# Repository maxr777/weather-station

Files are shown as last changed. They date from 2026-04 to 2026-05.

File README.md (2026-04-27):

# Weather Station
ESP32-based weather station built with ESP-IDF, no third-party sensor libraries. A handmade rewrite of an earlier Arduino IDE version that relied on libraries. Also taken further: soldered onto a perfboard with a 3D printed enclosure instead of a breadboard.

Reads temperature, humidity, and pressure via a BME280 over I2C, monitors air quality with a PMS5003 over UART, and displays everything on an SH1106 OLED. A few diagnostic LEDs signal hardware faults on startup.

All sensor drivers written from scratch against the datasheets. Structured as pure header-only libraries — an experiment after building projects with both the classic .h/.c split and unity builds. Uses Raylib naming conventions - I'd use [Tiger Style](https://tigerstyle.dev/#nouns-and-verbs) if starting it today. Font by [petabyt](https://github.com/petabyt/font). Startup logo generated with Claude.

## Demo

*Low res thumbnails — click to watch on YouTube*

Breadboard demo (https://youtu.be/4yA_y9Lus5Y)

Perfboard build (https://youtu.be/DK9z5tJ5IRI)

## Schematic
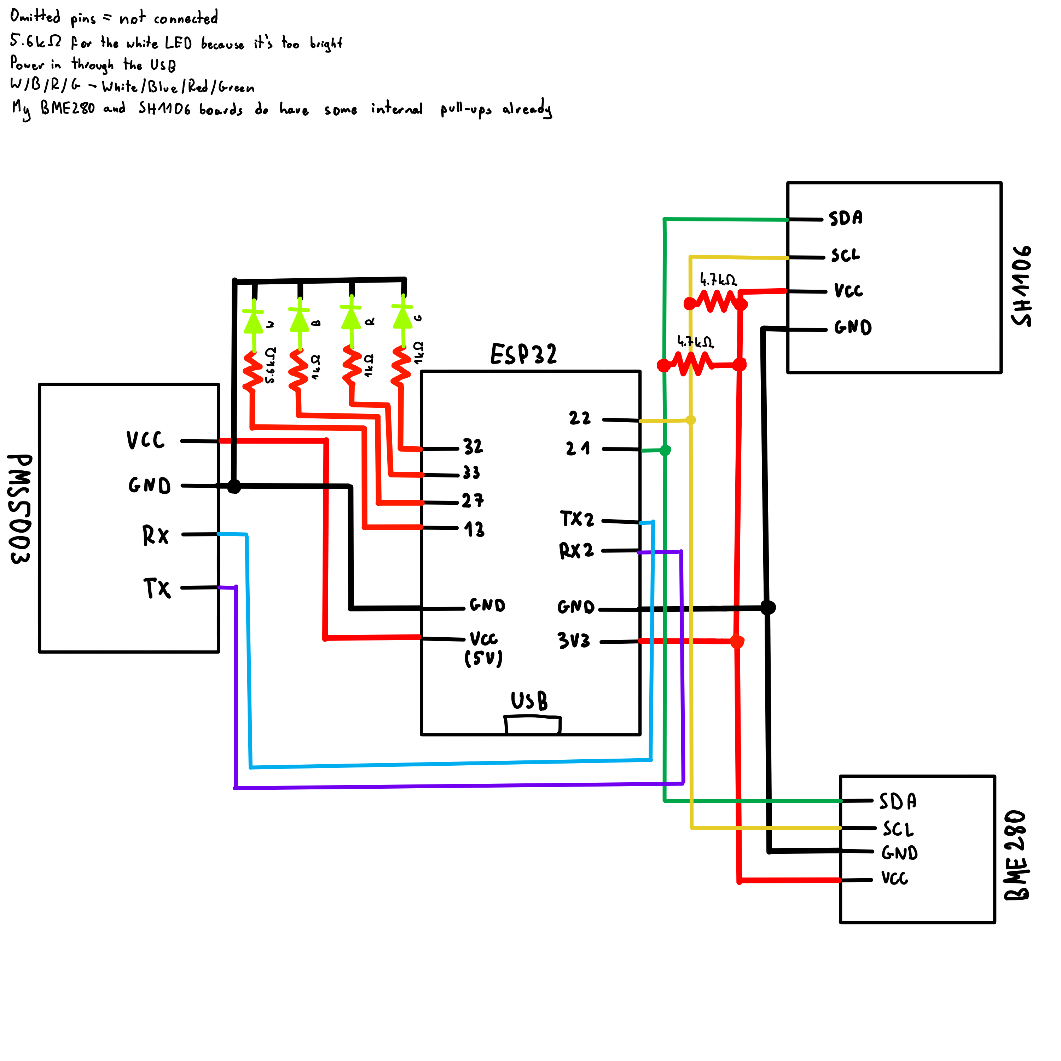
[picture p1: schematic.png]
Schematic


## Build
`idf.py build flash monitor` (run from the root directory, not `main/`)

## Notes
- Enum names ended up too verbose - need to be more conservative with it
- Tiger Style's big-endian naming is so much better (`BME280_setup()` over `setup_BME280()`) - it reads better and works great with autocomplete
- camelCase is harder to read and is a headache sometimes (e.g. `0` followed by `O`, or `GetLEDGPIO`) - definitely use snake_case

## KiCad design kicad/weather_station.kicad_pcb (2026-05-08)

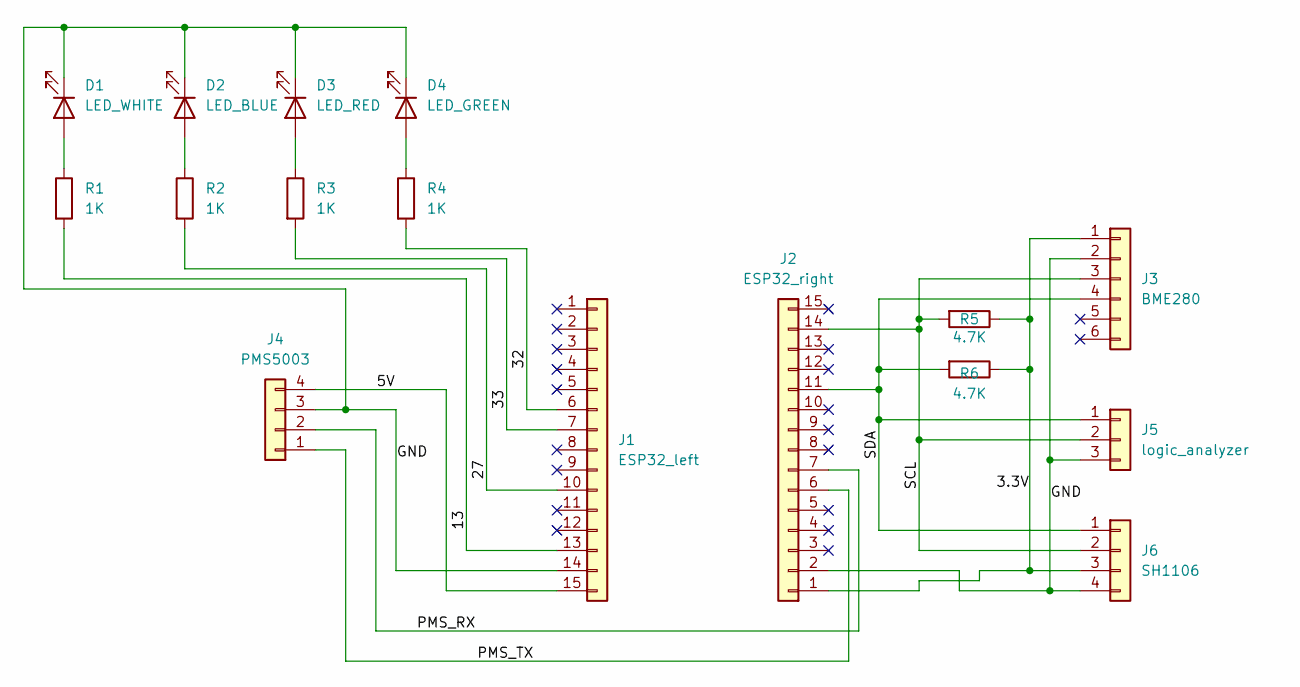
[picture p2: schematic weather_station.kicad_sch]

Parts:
D1: LED_WHITE; LED_0805_2012Metric
D2: LED_BLUE; LED_0805_2012Metric
D3: LED_RED; LED_0805_2012Metric
D4: LED_GREEN; LED_0805_2012Metric
J1: ESP32_left; PinHeader_1x15_P2.54mm_Vertical
J2: ESP32_right; PinHeader_1x15_P2.54mm_Vertical
J3: BME280; PinHeader_1x06_P2.54mm_Vertical
J4: PMS5003; PinHeader_1x04_P2.54mm_Vertical
J5: logic_analyzer; PinHeader_1x03_P2.54mm_Vertical
J6: SH1106; PinHeader_1x04_P2.54mm_Vertical
R1, R2, R3, R4: 1K; R_0805_2012Metric
R5, R6: 4.7K; R_0805_2012Metric

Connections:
/3.3V: J2.1, J3.1, J6.3, R5.1, R6.1
/5V: J1.15, J4.4
/13: J1.13, R1.2
/27: J1.10, R2.2
/32: J1.6, R4.2
/33: J1.7, R3.2
/GND: D1.1 (K), D2.1 (K), D3.1 (K), D4.1 (K), J1.14, J2.2, J3.2, J4.3, J5.3, J6.4
/PMS_RX: J2.7, J4.2
/PMS_TX: J2.6, J4.1
/SCL: J2.14, J3.3, J5.2, J6.2, R5.2
/SDA: J2.11, J3.4, J5.1, J6.1, R6.2
unnamed: D1.2 (A), R1.1
unnamed: D2.2 (A), R2.1
unnamed: D3.2 (A), R3.1
unnamed: D4.2 (A), R4.1

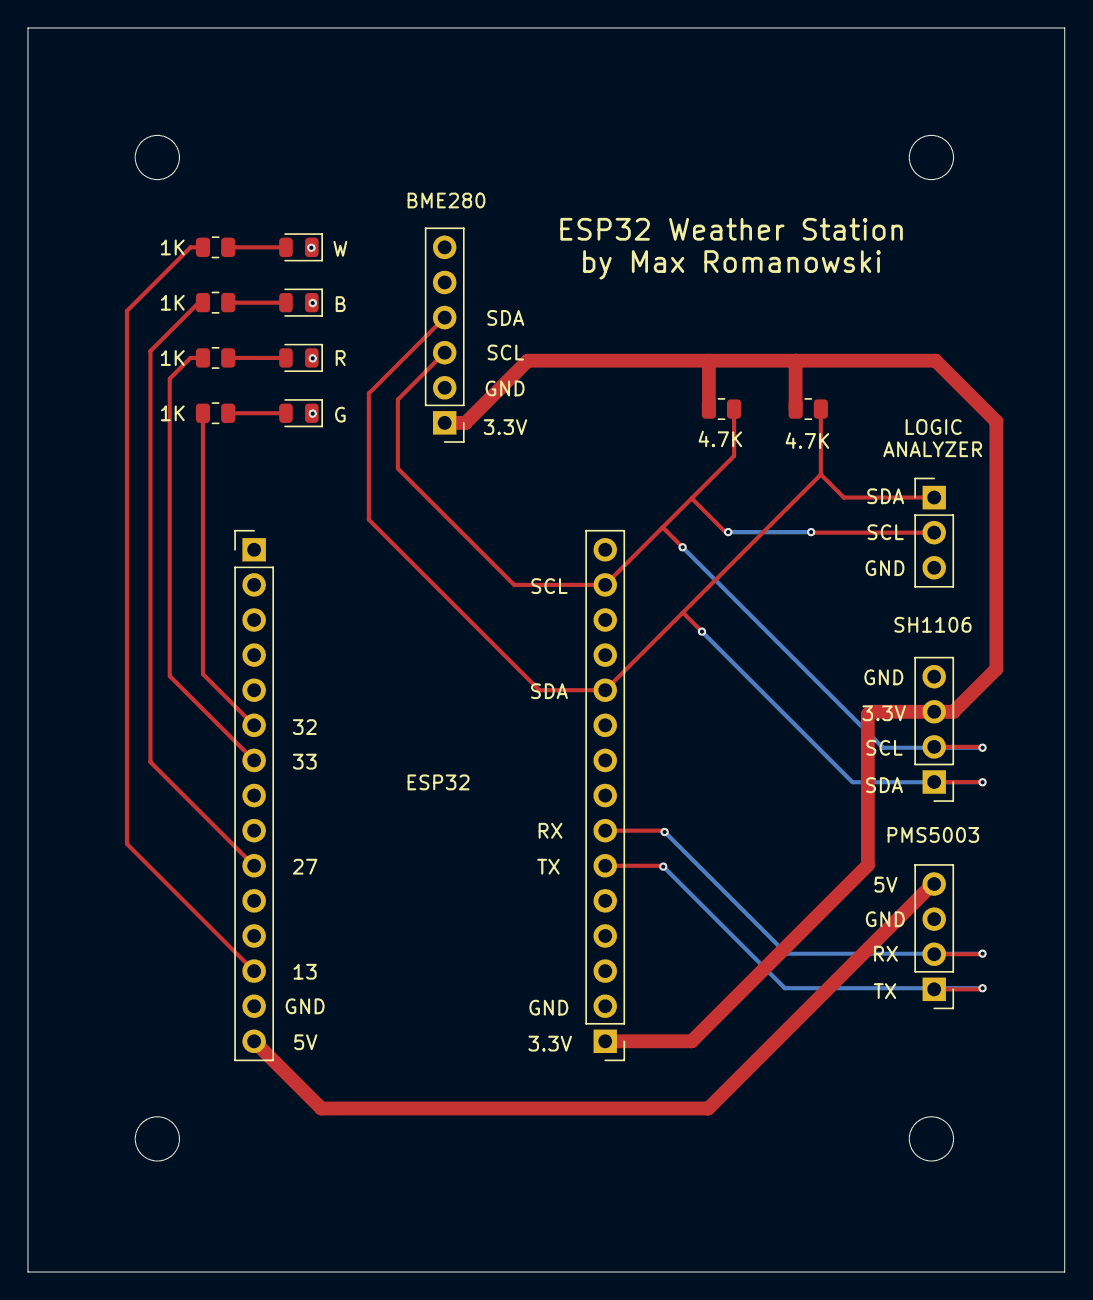
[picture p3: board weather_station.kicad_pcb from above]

Board: 2 copper layers, 75.0 x 90.0 mm, 20 parts (0 on the bottom side), 15 nets.

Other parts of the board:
H1, H2, H3, H4: MountingHole_3.2mm_M3

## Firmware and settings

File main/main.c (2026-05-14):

#include "bme280.h"
#include "driver/gpio.h"
#include "driver/i2c_master.h"
#include "freertos/FreeRTOS.h"
#include "freertos/task.h"
#include "led.h"
#include "pms5003.h"
#include "sh1106.h"
#include <stdio.h>

void app_main(void) {
	// Setup the LED GPIOs as output
	gpio_reset_pin(WHITE_LED_GPIO);
	gpio_set_direction(WHITE_LED_GPIO, GPIO_MODE_OUTPUT);
	gpio_reset_pin(BLUE_LED_GPIO);
	gpio_set_direction(BLUE_LED_GPIO, GPIO_MODE_OUTPUT);
	gpio_reset_pin(RED_LED_GPIO);
	gpio_set_direction(RED_LED_GPIO, GPIO_MODE_OUTPUT);
	gpio_reset_pin(GREEN_LED_GPIO);
	gpio_set_direction(GREEN_LED_GPIO, GPIO_MODE_OUTPUT);

	// Setup the i2c bus
	i2c_master_bus_config_t busConfig = {};
	busConfig.i2c_port = -1;
	busConfig.sda_io_num = 21;
	busConfig.scl_io_num = 22;
	busConfig.clk_source = I2C_CLK_SRC_DEFAULT;
	busConfig.glitch_ignore_cnt = 7;
	busConfig.intr_priority = 0;
	busConfig.trans_queue_depth = 0;
	busConfig.flags.enable_internal_pullup = 1;
	busConfig.flags.allow_pd = 0;

	i2c_master_bus_handle_t masterBusHandle;
	ESP_ERROR_CHECK(i2c_new_master_bus(&busConfig, &masterBusHandle));

	// Setup the sensors
	EnableLED(WHITE);
	SH1106 sh1106 = SetupSH1106(masterBusHandle);

	EnableLED(BLUE);
	BME280 bme280 = SetupBME280(masterBusHandle);

	EnableLED(RED);
	PMS5003 pms5003 = SetupPMS5003();

	EnableLED(GREEN);
	vTaskDelay(pdMS_TO_TICKS(1000));

	DisableLED(WHITE);
	DisableLED(BLUE);
	DisableLED(RED);
	DisableLED(GREEN);

	while (true) {
		GetWeatherReadingsErrorCodes BME280ErrorCode = GetWeatherReadings(&bme280);
		GetAirQualityErrorCodes PMS5003ErrorCode = GetAirQuality(&pms5003);

		char temp[20];
		char humidity[20];
		char pressure[20];
		char pm10[20];
		char pm25[20];
		char pm100[20];

		if (BME280ErrorCode == BME_OK) {
			snprintf(temp, sizeof(temp), "T: %.0f C", bme280.temperature);
			snprintf(humidity, sizeof(humidity), "H: %.0f%%", bme280.humidity);
			snprintf(pressure, sizeof(pressure), "P: %.0f hPa", bme280.pressure / 100);
			DisableLED(BLUE);
		} else {
			ESP_LOGE("BME280", "%s", GetWeatherReadingsErrorCodesToStr(BME280ErrorCode));
			EnableLED(BLUE);
			snprintf(temp, sizeof(temp), "T: %.0f C*", bme280.temperature);
			snprintf(humidity, sizeof(humidity), "H: %.0f%%*", bme280.humidity);
			snprintf(pressure, sizeof(pressure), "P: %.0f hPa*", bme280.pressure / 100);
			RestartBME280(masterBusHandle, &bme280);
		}

		if (PMS5003ErrorCode == PMS_OK) {
			DisableLED(RED);
			snprintf(pm10, sizeof(pm10), "PM 1.0: %d (%s)", pms5003.pm10,
				 GetPM10Quality(pms5003.pm10));
			snprintf(pm25, sizeof(pm25), "PM 2.5: %d (%s)", pms5003.pm25,
				 GetPM25Quality(pms5003.pm25));
			snprintf(pm100, sizeof(pm100), "PM 10:  %d (%s)", pms5003.pm100,
				 GetPM100Quality(pms5003.pm100));
		} else {
			ESP_LOGE("PMS5003", "%s", GetAirQualityErrorCodesToStr(PMS5003ErrorCode));
			EnableLED(RED);
			snprintf(pm10, sizeof(pm10), "PM 1.0: %d (%s)*", pms5003.pm10,
				 GetPM10Quality(pms5003.pm10));
			snprintf(pm25, sizeof(pm25), "PM 2.5: %d (%s)*", pms5003.pm25,
				 GetPM25Quality(pms5003.pm25));
			snprintf(pm100, sizeof(pm100), "PM 10:  %d (%s)*", pms5003.pm100,
				 GetPM100Quality(pms5003.pm100));
		}

		SH1106ClearScreen(&sh1106);
		SH1106PrintText(&sh1106, temp, 1);
		SH1106PrintText(&sh1106, humidity, 2);
		SH1106PrintText(&sh1106, pressure, 3);
		SH1106PrintText(&sh1106, pm10, 4);
		SH1106PrintText(&sh1106, pm25, 5);
		SH1106PrintText(&sh1106, pm100, 6);
		SH1106FlushErrorCodes SH1106ErrorCode = SH1106Flush(&sh1106);
		if (SH1106ErrorCode != SH_OK) {
			ESP_LOGE("SH1106", "%s", FlushErrorCodesToStr(SH1106ErrorCode));
			EnableLED(WHITE);
		} else {
			DisableLED(WHITE);
		}

		fflush(stdout);
		vTaskDelay(1000 / portTICK_PERIOD_MS);
	}
}

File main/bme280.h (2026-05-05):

#ifndef BME280_H
#define BME280_H

#include "driver/i2c_master.h"
#include "esp_log.h"
#include "esp_system.h"
#include "freertos/FreeRTOS.h"
#include "freertos/task.h"
#include "types.h"

#define BME280_ADDR 0x76

typedef struct {
	u16 T1;
	i16 T2;
	i16 T3;
	u16 P1;
	i16 P2;
	i16 P3;
	i16 P4;
	i16 P5;
	i16 P6;
	i16 P7;
	i16 P8;
	i16 P9;
	u8 H1;
	i16 H2;
	u8 H3;
	i16 H4;
	i16 H5;
	i8 H6;
} BME280Calibration;

typedef struct {
	i2c_master_dev_handle_t handle;
	i2c_device_config_t config;
	BME280Calibration offsets;
	// shared variable needed for pressure and humidity compensation
	i32 t_fine;
	float temperature;
	float humidity;
	float pressure;
} BME280;

static inline BME280 SetupBME280(i2c_master_bus_handle_t masterBusHandle) {
	BME280 bme = {};

	{
		bool boot = false;
		for (int i = 0; i < 5; ++i) {
			if (i2c_master_probe(masterBusHandle, BME280_ADDR, pdMS_TO_TICKS(100)) != ESP_OK) {
				ESP_LOGW("BME280", "Weather sensor not found, retrying...");
				vTaskDelay(pdMS_TO_TICKS(250));
			} else {
				boot = true;
				break;
			}
		}
		if (!boot) esp_restart();
	}

	bme.config.dev_addr_length = I2C_ADDR_BIT_LEN_7;
	bme.config.device_address = BME280_ADDR;
	bme.config.scl_speed_hz = 100000;

	ESP_ERROR_CHECK(i2c_master_bus_add_device(masterBusHandle, &bme.config, &bme.handle));

	// reset - write 0xB6 to 0xE0
	{
		uint8_t buf[2] = {0xE0, 0xB6};
		ESP_ERROR_CHECK(i2c_master_transmit(bme.handle, buf, 2, 100));

		// wait for the chip to come back
		vTaskDelay(pdMS_TO_TICKS(10));
	}

	// check chip id - read 0xD0, should be 0x60
	{
		uint8_t reg = 0xD0;
		uint8_t val = 0;
		ESP_ERROR_CHECK(i2c_master_transmit_receive(bme.handle, &reg, 1, &val, sizeof(val), 100));
		if (val != 0x60) {
			ESP_LOGE("BME280", "Wrong chip ID: expected 0x60, got 0x%02X", val);
			esp_restart();
		}
	}

	// read the offset values - they're used for calibration of each bme280, as there are factory variances
	// so you apply the offsets to the raw values you get the get the actual values
	{
		u8 reg = 0x88;
		u8 raw[24];
		ESP_ERROR_CHECK(i2c_master_transmit_receive(bme.handle, &reg, 1, raw, sizeof(raw), 100));

		bme.offsets.T1 = (u16)((u16)raw[1] << 8 | raw[0]);
		bme.offsets.T2 = (i16)((u16)raw[3] << 8 | raw[2]);
		bme.offsets.T3 = (i16)((u16)raw[5] << 8 | raw[4]);
		bme.offsets.P1 = (u16)((u16)raw[7] << 8 | raw[6]);
		bme.offsets.P2 = (i16)((u16)raw[9] << 8 | raw[8]);
		bme.offsets.P3 = (i16)((u16)raw[11] << 8 | raw[10]);
		bme.offsets.P4 = (i16)((u16)raw[13] << 8 | raw[12]);
		bme.offsets.P5 = (i16)((u16)raw[15] << 8 | raw[14]);
		bme.offsets.P6 = (i16)((u16)raw[17] << 8 | raw[16]);
		bme.offsets.P7 = (i16)((u16)raw[19] << 8 | raw[18]);
		bme.offsets.P8 = (i16)((u16)raw[21] << 8 | raw[20]);
		bme.offsets.P9 = (i16)((u16)raw[23] << 8 | raw[22]);

		u8 h1reg = 0xA1;
		ESP_ERROR_CHECK(i2c_master_transmit_receive(bme.handle, &h1reg, 1, &bme.offsets.H1, sizeof(bme.offsets.H1), 100));

		u8 hreg = 0xE1;
		u8 hraw[7];
		ESP_ERROR_CHECK(i2c_master_transmit_receive(bme.handle, &hreg, 1, hraw, sizeof(hraw), 100));

		bme.offsets.H2 = (i16)((u16)hraw[1] << 8 | hraw[0]);
		bme.offsets.H3 = hraw[2];
		bme.offsets.H4 = (i16)((i8)hraw[3] << 4 | (hraw[4] & 0x0F));
		bme.offsets.H5 = (i16)((i8)hraw[5] << 4 | (hraw[4] >> 4));
		bme.offsets.H6 = (i8)hraw[6];
	}

	// set the humidity oversampling to x1
	// oversampling - how many times the sensors sample before giving a reading
	// x1 - one raw sample, higher = less noise but takes longer and uses more power
	{
		u8 buf[2] = {0xF2, 0x01};
		ESP_ERROR_CHECK(i2c_master_transmit(bme.handle, buf, sizeof(buf), 100));
	}

	// set the temperature oversampling to x2
	// set the pressure oversampling to x1
	// set it to normal mode (auto toggles between measuring and standby)
	{
		u8 buf[2] = {0xF4, 0x27};
		ESP_ERROR_CHECK(i2c_master_transmit(bme.handle, buf, sizeof(buf), 100));
	}

	// set the standby time to 1000ms (1s wait in between measurements)
	// set the filter to off (give raw values, no smoothing of sudden spikes)
	{
		u8 buf[2] = {0xF5, 0xA0};
		ESP_ERROR_CHECK(i2c_master_transmit(bme.handle, buf, sizeof(buf), 100));
	}

	return bme;
}

static inline void RestartBME280(i2c_master_bus_handle_t masterBusHandle, BME280 *bme) {
	i2c_master_bus_rm_device(bme->handle);

	memset(&bme->handle, 0, sizeof(bme->handle));
	memset(&bme->config, 0, sizeof(bme->config));
	memset(&bme->offsets, 0, sizeof(bme->offsets));
	bme->t_fine = 0;

	while (i2c_master_probe(masterBusHandle, BME280_ADDR, pdMS_TO_TICKS(100)) != ESP_OK) {
		ESP_LOGW("BME280", "Weather sensor not found");
		return;
	}

	bme->config.dev_addr_length = I2C_ADDR_BIT_LEN_7;
	bme->config.device_address = BME280_ADDR;
	bme->config.scl_speed_hz = 100000;

	i2c_master_bus_add_device(masterBusHandle, &bme->config, &bme->handle);

	// reset - write 0xB6 to 0xE0
	{
		uint8_t buf[2] = {0xE0, 0xB6};
		i2c_master_transmit(bme->handle, buf, 2, 100);

		// wait for the chip to come back
		vTaskDelay(pdMS_TO_TICKS(10));
	}

	// check chip id - read 0xD0, should be 0x60
	{
		uint8_t reg = 0xD0;
		uint8_t val = 0;
		i2c_master_transmit_receive(bme->handle, &reg, 1, &val, sizeof(val), 100);
		if (val != 0x60) {
			ESP_LOGE("BME280", "Wrong chip ID: expected 0x60, got 0x%02X", val);
			return;
		}
	}

	// read the offset values - they're used for calibration of each bme280, as there are factory variances
	// so you apply the offsets to the raw values you get the get the actual values
	{
		u8 reg = 0x88;
		u8 raw[24];
		i2c_master_transmit_receive(bme->handle, &reg, 1, raw, sizeof(raw), 100);

		bme->offsets.T1 = (u16)((u16)raw[1] << 8 | raw[0]);
		bme->offsets.T2 = (i16)((u16)raw[3] << 8 | raw[2]);
		bme->offsets.T3 = (i16)((u16)raw[5] << 8 | raw[4]);
		bme->offsets.P1 = (u16)((u16)raw[7] << 8 | raw[6]);
		bme->offsets.P2 = (i16)((u16)raw[9] << 8 | raw[8]);
		bme->offsets.P3 = (i16)((u16)raw[11] << 8 | raw[10]);
		bme->offsets.P4 = (i16)((u16)raw[13] << 8 | raw[12]);
		bme->offsets.P5 = (i16)((u16)raw[15] << 8 | raw[14]);
		bme->offsets.P6 = (i16)((u16)raw[17] << 8 | raw[16]);
		bme->offsets.P7 = (i16)((u16)raw[19] << 8 | raw[18]);
		bme->offsets.P8 = (i16)((u16)raw[21] << 8 | raw[20]);
		bme->offsets.P9 = (i16)((u16)raw[23] << 8 | raw[22]);

		u8 h1reg = 0xA1;
		i2c_master_transmit_receive(bme->handle, &h1reg, 1, &bme->offsets.H1, sizeof(bme->offsets.H1), 100);

		u8 hreg = 0xE1;
		u8 hraw[7];
		i2c_master_transmit_receive(bme->handle, &hreg, 1, hraw, sizeof(hraw), 100);

		bme->offsets.H2 = (i16)((u16)hraw[1] << 8 | hraw[0]);
		bme->offsets.H3 = hraw[2];
		bme->offsets.H4 = (i16)((i8)hraw[3] << 4 | (hraw[4] & 0x0F));
		bme->offsets.H5 = (i16)((i8)hraw[5] << 4 | (hraw[4] >> 4));
		bme->offsets.H6 = (i8)hraw[6];
	}

	// set the humidity oversampling to x1
	// oversampling - how many times the sensors sample before giving a reading
	// x1 - one raw sample, higher = less noise but takes longer and uses more power
	{
		u8 buf[2] = {0xF2, 0x01};
		i2c_master_transmit(bme->handle, buf, sizeof(buf), 100);
	}
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

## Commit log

2026-04-25 Can draw with SH1106. Need to tweak the MS for i2c writes in the SH1106Flush() function - for some reason even with pullup resistors, 100ms is still timing out
2026-04-25 Indicate bad/old values, log reading errors
    [bme280.h]
2026-04-26 Add schematic
2026-04-26 Fix schematic
2026-04-26 Fix schematic 2
2026-04-26 Fix schematic 3...
2026-04-26 Fix schematic 4
2026-05-08 Add kicad files
    [weather_station.kicad_pcb, weather_station.kicad_sch]
2026-05-14 Add SH1106 LED enable on error
    [main.c, pms5003.h]
